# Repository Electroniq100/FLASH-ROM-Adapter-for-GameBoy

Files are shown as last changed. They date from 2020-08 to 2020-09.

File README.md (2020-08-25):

# Mini version of SOP-32L FLASH to ROM Adapter for Game Boy Cartridges

This is a modified version of the SOP-32L FLASH to ROM Adapter for Game Boy Cartridges, it will fit in any cartridges without any modifications of the top shell of your cartridges.

## Compatible Flash Memory Chips

AM29F032@-#E* (4 MB)
or
AM29F016@-#E* (2 MB) Please note that for TSOP-48 version you will need to remove the 8 NC pins on each corner to get access to the pads.
```
 @ = Manufactured process technology (None = 0.5 µm, B = 0.32 µm, D = 0.23 µm)
 # = any speeds are compatible (75,90,120,150)
 E = 48-Pin Thin Small Outline Package (TSOP) Standard Pinout (TS 048)
 * = any temperature range (C = Commercial (0°C to +70°C) or I = Industrial (-40°C to +85°C))
```
*Ex: AM29F016-75EC, AM29F032B-120EI,...* 

---

## [How To - Assembly Guide](http://www.jrodrigo.net/wiki/how-to-diy-a-gameboy-flash-cartridge-with-a-rom-adapter-board/)

## Where to buy :package:
- [**OSHpark** (Mini Version SOP32 bare PCBs)](https://oshpark.com/shared_projects/QGnPTqav)

---

## License
#### Licenced under [Creative Commons - Attribution and Share Alike](https://github.com/JRodrigoTech/FLASH-ROM-Adapter-for-GameBoy/blob/master/LICENSE.md) by [J.Rodrigo](http://www.jrodrigo.net)

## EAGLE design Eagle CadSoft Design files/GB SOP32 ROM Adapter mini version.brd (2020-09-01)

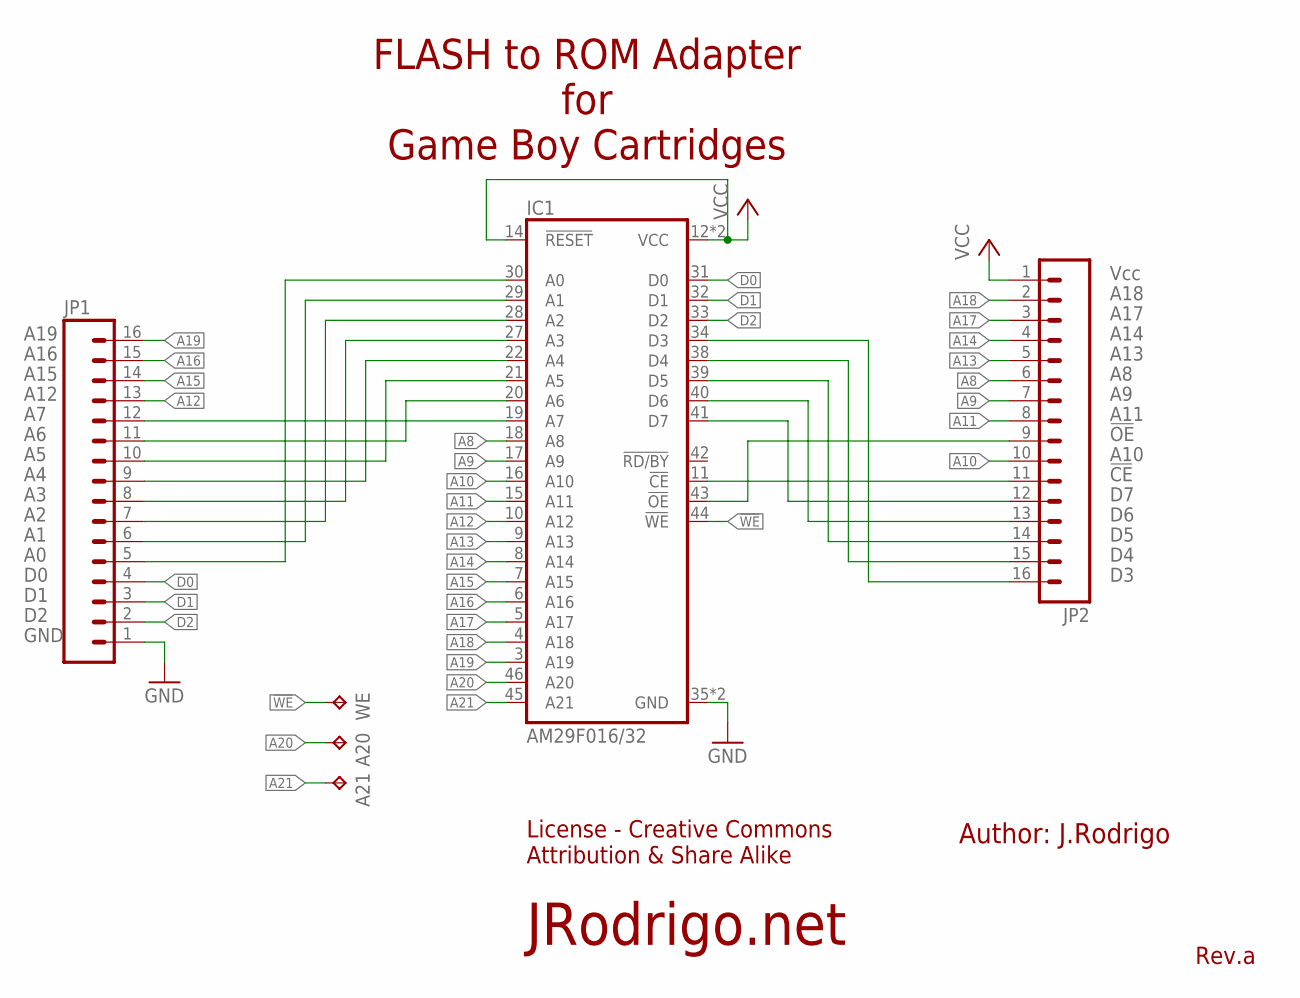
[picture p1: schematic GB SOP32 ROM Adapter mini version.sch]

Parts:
A20, A21: TPTP06SQ; TP06SQ
IC1: AM29F016/32; TSOP48_WITHOUT_NC
JP1, JP2: CASTELLATIONS_16-PINS*; CASTELLATIONS_16-PINS
WE: TPTP06SQ; TP06SQ

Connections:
!WE: IC1.44 (!WE), WE.TP
A8: IC1.18 (A8), JP2.6
A9: IC1.17 (A9), JP2.7
A10: IC1.16 (A10), JP2.10
A11: IC1.15 (A11), JP2.8
A12: IC1.10 (A12), JP1.13
A13: IC1.9 (A13), JP2.5
A14: IC1.8 (A14), JP2.4
A15: IC1.7 (A15), JP1.14
A16: IC1.6 (A16), JP1.15
A17: IC1.5 (A17), JP2.3
A18: IC1.4 (A18), JP2.2
A19: IC1.3 (A19), JP1.16
A20: A20.TP, IC1.46 (A20)
A21: A21.TP, IC1.45 (A21)
D0: IC1.31 (D0), JP1.4
D1: IC1.32 (D1), JP1.3
D2: IC1.33 (D2), JP1.2
GND: IC1.35 (GND), IC1.36 (GND), JP1.1
unnamed: IC1.34 (D3), JP2.16
unnamed: IC1.38 (D4), JP2.15
unnamed: IC1.39 (D5), JP2.14
unnamed: IC1.40 (D6), JP2.13
unnamed: IC1.41 (D7), JP2.12
unnamed: IC1.11 (!CE), JP2.11
unnamed: IC1.43 (!OE), JP2.9
unnamed: IC1.29 (A1), JP1.6
unnamed: IC1.28 (A2), JP1.7
unnamed: IC1.30 (A0), JP1.5
unnamed: IC1.27 (A3), JP1.8
unnamed: IC1.22 (A4), JP1.9
unnamed: IC1.21 (A5), JP1.10
unnamed: IC1.20 (A6), JP1.11
unnamed: IC1.19 (A7), JP1.12
VCC: IC1.12 (VCC), IC1.14 (!RESET), IC1.37 (VCC), JP2.1

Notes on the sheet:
A19
A16
A15
A12
GND
Vcc
A18
A17
A14
A13
A11
!OE
A10
!CE
FLASH to ROM Adapter for Game Boy Cartridges
Rev.a
Author: J.Rodrigo
License - Creative Commons Attribution & Share Alike
JRodrigo.net

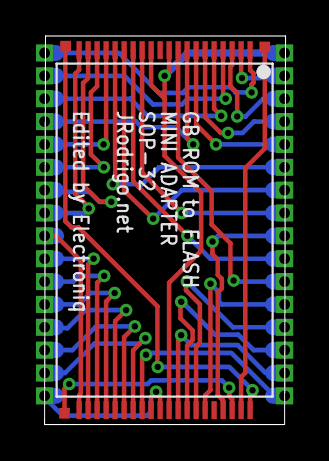
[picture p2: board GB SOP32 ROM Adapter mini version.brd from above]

Board: 2 copper layers, 13.4 x 21.6 mm, 6 parts (0 on the bottom side), 35 nets.
